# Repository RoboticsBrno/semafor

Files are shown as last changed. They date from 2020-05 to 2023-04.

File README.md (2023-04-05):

# Semafor

Traffic light gadget for outdoor games designed for [Helceletka.cz](https://helceletka.cz/).

## Hardware
Board is based on [ESP8266](https://en.wikipedia.org/wiki/ESP8266) microcontroller and large LEDs. It is powered by our power bank and can be managed via WiFi from the user's phone.

## Software
The software is written in [PlatformIO](https://platformio.org/) and is based on the Arduino framework.

<div align="center">
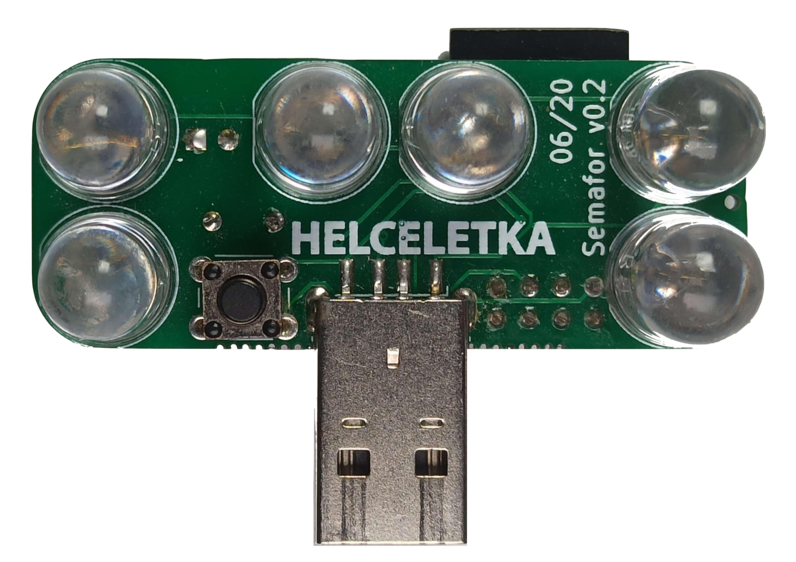
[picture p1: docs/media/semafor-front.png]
  	<td></td>
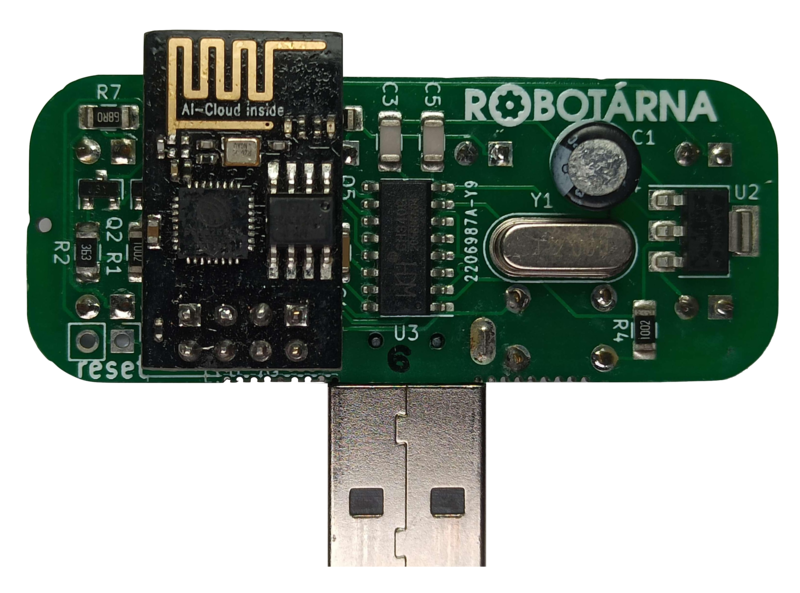
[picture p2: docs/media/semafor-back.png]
	<td></td>
</div>

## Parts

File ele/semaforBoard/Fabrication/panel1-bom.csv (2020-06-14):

Id | Designator | Package | Quantity | Designation | Supplier and ref
1 | REF**,REF**,REF**,REF**,REF**,REF**,REF**,REF**,REF**,REF**,REF**,REF**,REF**,REF**,REF**,REF**,REF**,REF**,REF**,REF**,REF**,REF**,REF**,REF**,REF**,REF**,REF**,REF**,REF**,REF**,REF**,REF**,REF**,REF**,REF**,REF**,REF**,REF**,REF**,REF**,REF**,REF**,REF**,REF**,REF**,REF**,REF**,REF**,REF**,REF**,REF**,REF**,REF**,REF**,REF**,REF**,REF**,REF**,REF**,REF**,REF**,REF**,REF**,REF**,REF**,REF**,REF**,REF**,REF**,REF**,REF**,REF**,REF**,REF**,REF**,REF**,REF**,REF**,REF**,REF**,REF**,REF**,REF**,REF**,REF**,REF**,REF**,REF**,REF**,REF**,REF**,REF**,REF**,REF**,REF**,REF**,REF**,REF**,REF**,REF**,REF**,REF**,REF**,REF**,REF**,REF**,REF**,REF** | NPTH | 108 | NPTH
2 | J1,J1,J1,J1 | PinHeader_1x02_P2.54mm_Vertical | 4 | RESET
3 | D6,D5,D4,D3,D2,D1,D6,D5,D4,D3,D2,D1,D6,D5,D4,D3,D2,D1,D6,D5,D4,D3,D2,D1 | LED_D10.0mm | 24 | LED
4 | Y1,Y1,Y1,Y1 | Crystal_HC49-4H_Vertical | 4 | Crystal
5 | U3,U3,U3,U3 | SOIC-16_3.9x9.9mm_P1.27mm | 4 | CH340G
6 | R10,R4,R3,R2,R1,R10,R4,R3,R2,R1,R10,R4,R3,R2,R1,R10,R4,R3,R2,R1 | R_1206_3216Metric_Pad1.42x1.75mm_HandSolder | 20 | 10k
7 | Q5,Q4,Q3,Q2,Q1,Q5,Q4,Q3,Q2,Q1,Q5,Q4,Q3,Q2,Q1,Q5,Q4,Q3,Q2,Q1 | SOT-23 | 20 | BC817
8 | C5,C3,C5,C3,C5,C3,C5,C3 | C_1206_3216Metric_Pad1.42x1.75mm_HandSolder | 8 | 22pF
9 | C4,C2,C4,C2,C4,C2,C4,C2 | C_1206_3216Metric_Pad1.42x1.75mm_HandSolder | 8 | 100nF
10 | G1,G***,G1,G***,G1,G***,G1,G*** | Robotarna | 8 | LOGO
11 | G2,G2,G2,G2 | Helceletka | 4 | LOGO
12 | J3,J3,J3,J3 | USB_A_CNCTech_1001-011-01101_Horizontal | 4 | USB_A
13 | U1,U1,U1,U1 | ESP-01 | 4 | ESP-01
14 | U2,U2,U2,U2 | SOT-223-3_TabPin2 | 4 | AMS1117-3.3
15 | SW1,SW1,SW1,SW1 | SW_PUSH_6mm | 4 | SW_Push
16 | R9,R8,R9,R8,R9,R8,R9,R8 | R_1206_3216Metric_Pad1.42x1.75mm_HandSolder | 8 | 1k
17 | R7,R6,R5,R7,R6,R5,R7,R6,R5,R7,R6,R5 | R_1206_3216Metric_Pad1.42x1.75mm_HandSolder | 12 | 75R
18 | C1,C1,C1,C1 | CP_Radial_D6.3mm_P2.50mm | 4 | 47uF

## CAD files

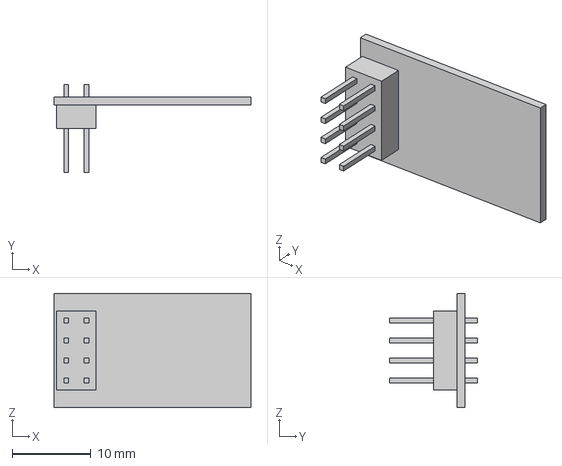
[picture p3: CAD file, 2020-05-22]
hw/ESP-01-fixed v3.step
25.0 x 11.2 x 14.5 mm

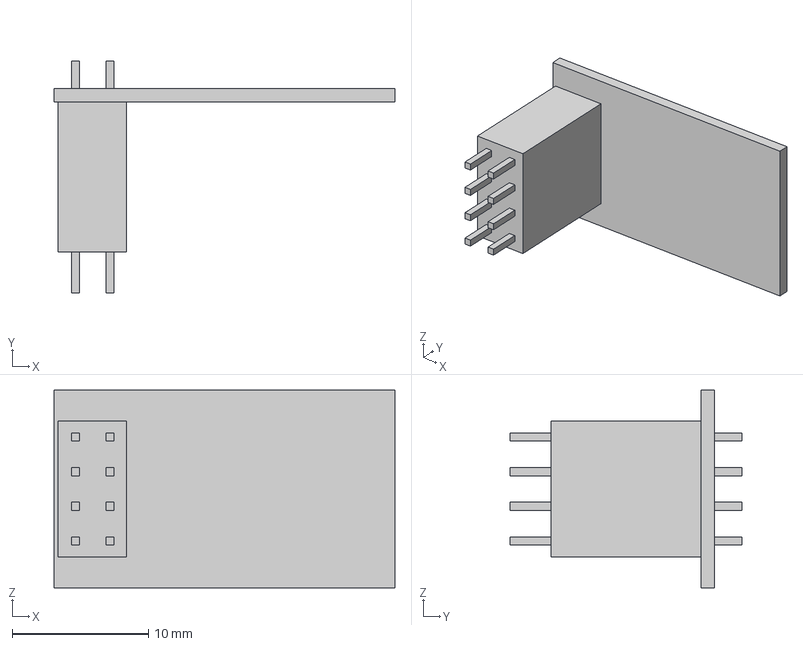
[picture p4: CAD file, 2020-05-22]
hw/ESP-01-detachable v2.step
25.0 x 17.0 x 14.5 mm

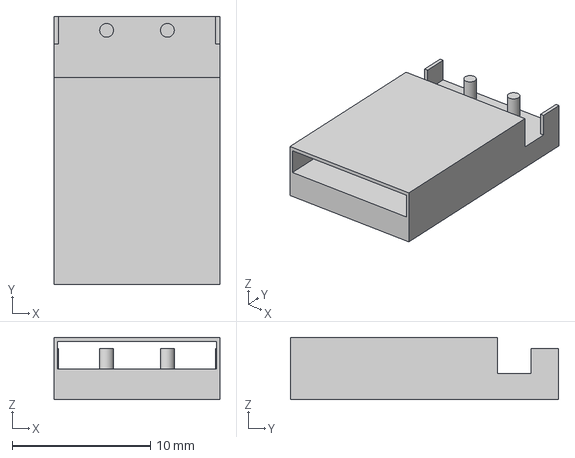
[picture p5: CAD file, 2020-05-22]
hw/USB_A_female_CNCTECH v2.step
12.0 x 19.4 x 4.50 mm

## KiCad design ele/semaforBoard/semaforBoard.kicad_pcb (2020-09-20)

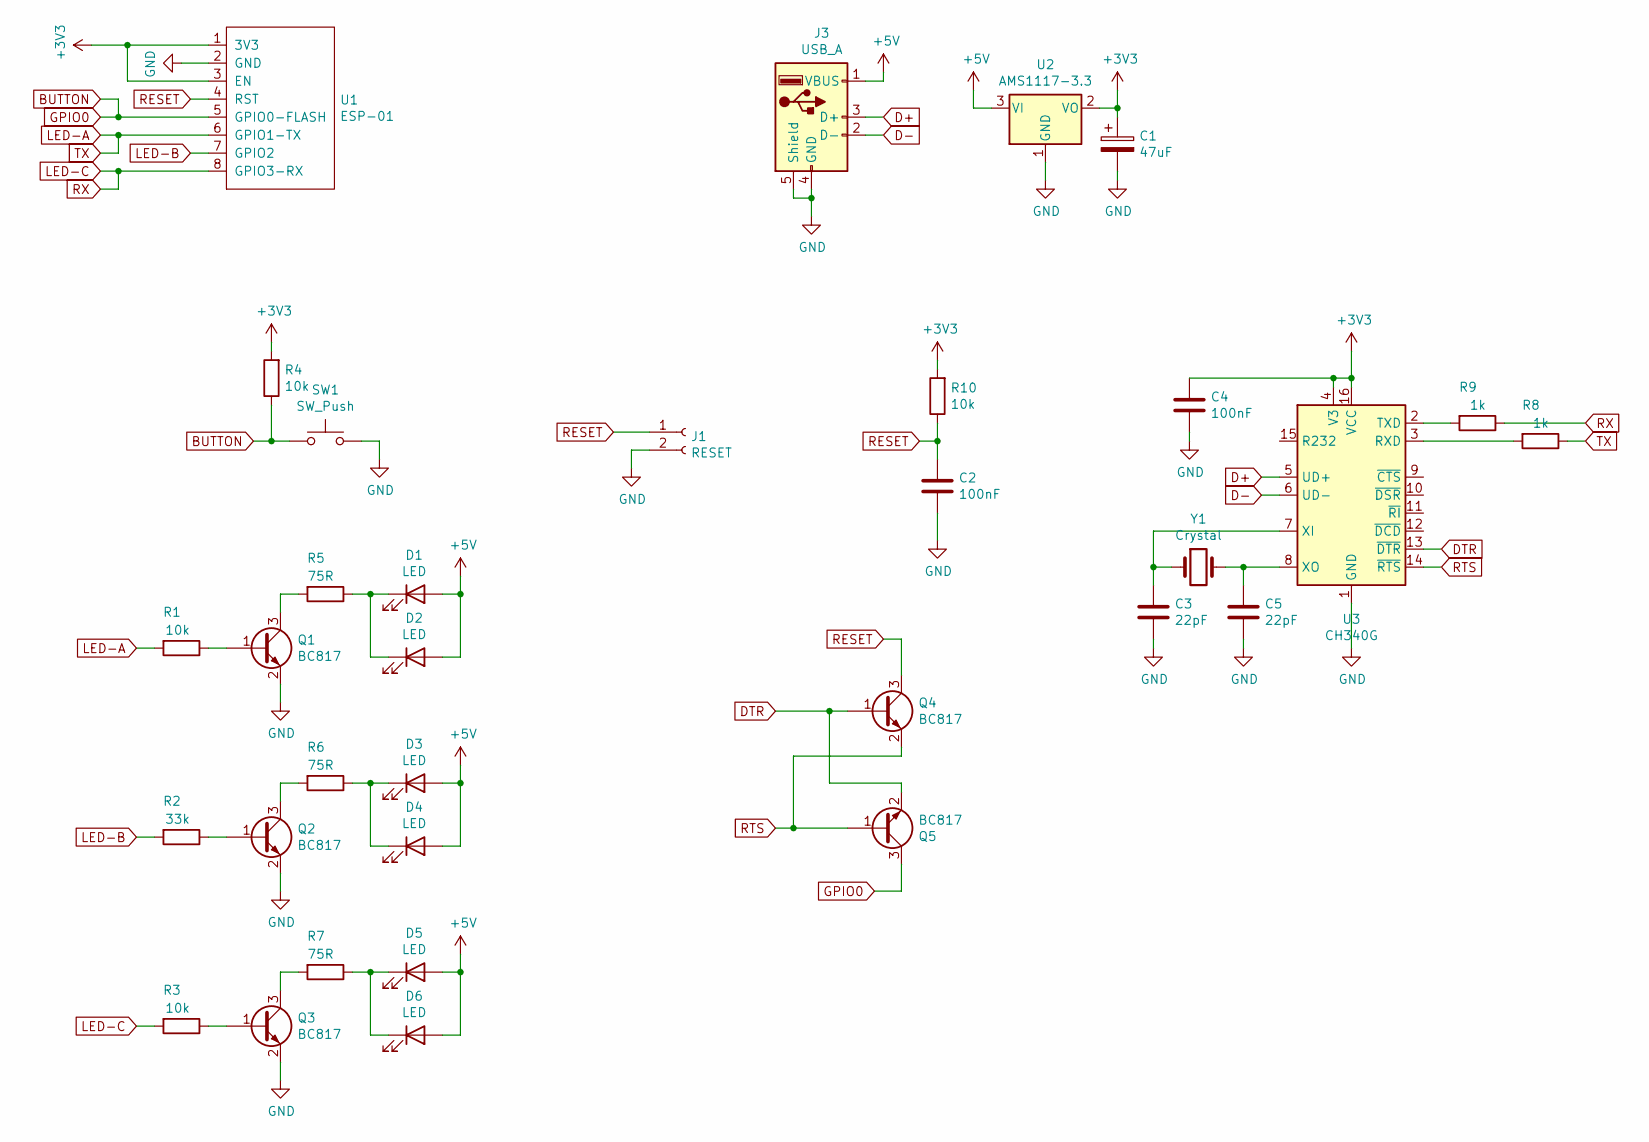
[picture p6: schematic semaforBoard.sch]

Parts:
C1: 47uF; CP_Radial_D6.3mm_P2.50mm
C2, C4: 100nF; C_1206_3216Metric_Pad1.42x1.75mm_HandSolder
C3, C5: 22pF; C_1206_3216Metric_Pad1.42x1.75mm_HandSolder
D1, D2, D3, D4, D5, D6: LED; LED_D10.0mm
J1: RESET; PinHeader_1x02_P2.54mm_Vertical
J3: USB_A; USB_A_CNCTech_1001-011-01101_Horizontal
Q1, Q2, Q3, Q4, Q5: BC817; SOT-23
R1, R3, R4, R10: 10k; R_1206_3216Metric_Pad1.42x1.75mm_HandSolder
R2: 33k; R_1206_3216Metric_Pad1.42x1.75mm_HandSolder
R5, R6, R7: 75R; R_1206_3216Metric_Pad1.42x1.75mm_HandSolder
R8, R9: 1k; R_1206_3216Metric_Pad1.42x1.75mm_HandSolder
SW1: SW_Push; SW_PUSH_6mm
U1: ESP-01
U2: AMS1117-3.3; SOT-223-3_TabPin2
U3: CH340G; SOIC-16_3.9x9.9mm_P1.27mm
Y1: Crystal; Crystal_HC49-4H_Vertical

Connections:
+3V3: C1.1, C4.1, R4.2, R10.2, U1.1 (3V3), U1.3 (EN), U2.2 (VO), U3.4 (V3), U3.16 (VCC)
+5V: D1.2 (A), D2.2 (A), D3.2 (A), D4.2 (A), D5.2 (A), D6.2 (A), J3.1 (VBUS), U2.3 (VI)
BUTTON: Q5.3 (C), R4.1, SW1.1, U1.5 (GPIO0-FLASH)
D+: J3.3 (D+), U3.5 (UD+)
D-: J3.2 (D-), U3.6 (UD-)
DTR: Q4.1 (B), Q5.2 (E), U3.13 (~DTR)
GND: C1.2, C2.2, C3.2, C4.2, C5.2, J1.2, J3.4 (GND), J3.5 (Shield), Q1.2 (E), Q2.2 (E), Q3.2 (E), SW1.2, U1.2 (GND), U2.1 (GND), U3.1 (GND)
LED-A: R1.2, R8.1, U1.6 (GPIO1-TX)
LED-B: R2.2, U1.7 (GPIO2)
LED-C: R3.2, R9.1, U1.8 (GPIO3-RX)
unnamed: C3.1, U3.7 (XI), Y1.1
unnamed: C5.1, U3.8 (XO), Y1.2
unnamed: D1.1 (K), D2.1 (K), R5.1
unnamed: D3.1 (K), D4.1 (K), R6.1
unnamed: D5.1 (K), D6.1 (K), R7.1
unnamed: Q1.1 (B), R1.1
unnamed: Q1.3 (C), R5.2
unnamed: Q2.1 (B), R2.1
unnamed: Q2.3 (C), R6.2
unnamed: Q3.1 (B), R3.1
unnamed: Q3.3 (C), R7.2
unnamed: R8.2, U3.3 (RXD)
unnamed: R9.2, U3.2 (TXD)
RESET: C2.1, J1.1, Q4.3 (C), R10.1, U1.4 (RST)
RTS: Q4.2 (E), Q5.1 (B), U3.14 (~RTS)

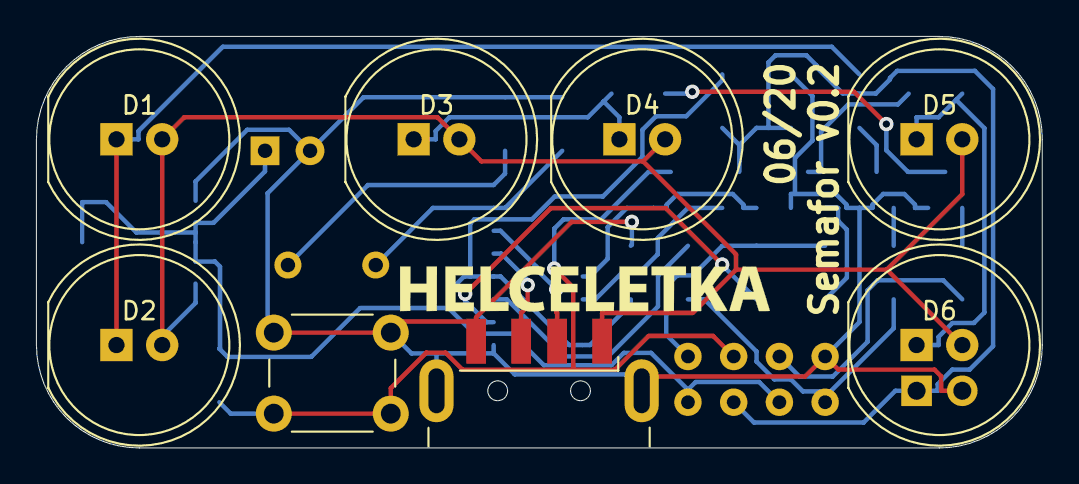
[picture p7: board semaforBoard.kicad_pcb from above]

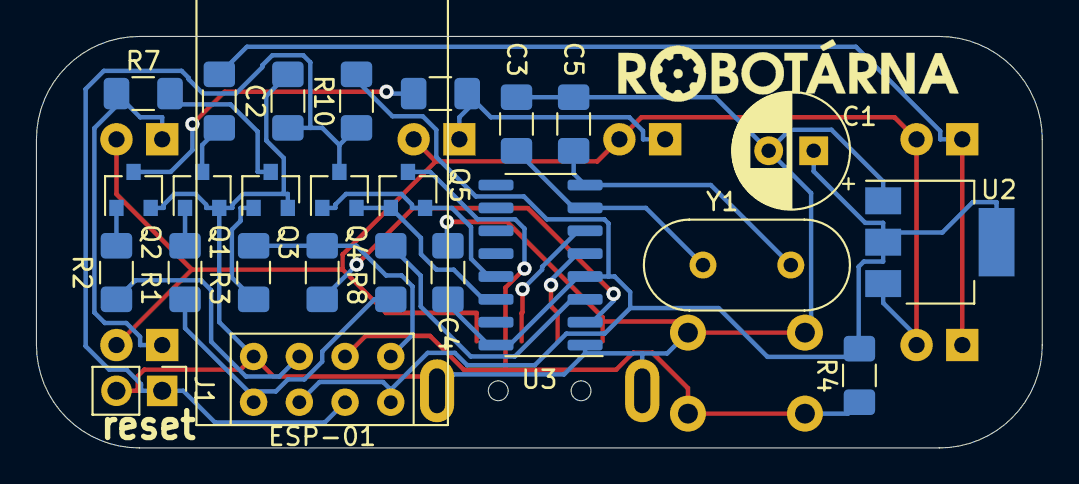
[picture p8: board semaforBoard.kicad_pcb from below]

Board: 2 copper layers, 55.9 x 22.9 mm, 35 parts (26 on the bottom side), 25 nets.

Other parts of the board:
G1: LOGO; Robotarna
G2: LOGO; Helceletka

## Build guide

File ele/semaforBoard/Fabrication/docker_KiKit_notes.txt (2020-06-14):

#Zavoláním následujícího příkazu ve složce, ve které je Dockerfile, se vytvoří image s tag kikit_docker_image
docker image build -t kikit_docker_image .

docker run -it -v D:/pcb:/pcb kikit_docker_image

kikit panelize extractboard --sourcearea 132 67 189 111 semaforBoard.kicad_pcb single.kicad_pcb

kikit panelize grid --space 2.5 --gridsize 4 1 --tabwidth 8 --tabheight 3 --htabs 1 --vtabs 2 --
mousebites 0.5 1 0.25 --radius 1 --tolerance 30 single.kicad_pcb panel1.kicad_pcb

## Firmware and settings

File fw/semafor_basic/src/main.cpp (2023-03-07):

#include "semafor.h"
#include "ArduinoMetronome.hpp"



void setup() {

    uint16_t periodCycle = 20;
    ArduinoMetronome loopMain(periodCycle);
    ArduinoMetronome loopPrint(10000);
    ArduinoMetronome loopSerialRead(50);

    semState sState;

    semaforInit();


    // while (digitalRead(button))
    // {
    //     setLedsAll(1);
    //     delay(50);
    // }

    sState = S_RECEIVE; // first start mode

    while (true)
    {
        dnsServer.processNextRequest();
        server.handleClient();

        if(loopPrint.loopMs()) {
            printInfo(sState);
        }

        if(loopMain.loopMs()) {

            switch (sState)
            {
            case S_RECEIVE:
                // Start game and wait for settings (this mode is automaticly deactivated after settings receive or 2 minutes)

                Serial.printf("\rS_RECEIVE");
                sState = semaforState(); //

                if(settReceive()) { // connec to mother`s ESP and receive settings
                    sState = S_NORMAL; // jump to normal mode after new settings receive
                }

                semaforLoop(); // run normal games parallel with settings receive
                break;

            case S_NORMAL:
                // Normal game mode - WiFi is off and game is running
                Serial.printf("\rS_NORMAL");
                semaforLoop();
                break;

            case S_BRODCAST:
                // Broadcast mode - WiFi is on and game is not running
                // ESP is in mother`s mode with enabled AP and broadcast settings to all ESPs
                // To exit from this mode unplugged power and restart ESP
                Serial.printf("\rS_BRODCAST");
                settBrodcast();
                break;
            }
        }
    }
}

void loop() {}

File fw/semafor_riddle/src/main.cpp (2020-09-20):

#include <ESP8266WiFi.h>
#include <WiFiClient.h>
#include <ESP8266WebServer.h>
#include <DNSServer.h>

#include "stateVector.h"
#include "EEPROM_data.h"
#include "handleHttp.h"

StateVector stateVector;
EEPROM_data stateVector_eeprom(&stateVector, sizeof(stateVector));

// DNS server
uint8_t DNS_PORT = 53;
DNSServer dnsServer;

// Web server
ESP8266WebServer server(80);

char *softAP_ssid = "Hadanka_Vedatori";
const char *softAP_password = "adminadmin";

uint8_t button = 0;   //IO, pulled up, boot fail if low
uint8_t ledPins[] = {1, 2, 3}; //R(TX), G, B(RX)

uint32_t prevCycle = 0;
uint16_t periodCycle = 20;
uint16_t debounce = 1000;
uint16_t flashPeriod = 100;
uint8_t state = 0;
uint32_t ledStateBegin = 0;


void setLed(uint8_t ledGPIO, bool on) {
    analogWrite(ledGPIO, on*stateVector.ledBrightness[0]*4);
}

void setup() {
    Serial.begin(115200);

    for(uint8_t i = 0; i < 3; ++i) {
        pinMode(ledPins[i], OUTPUT);
    }
    pinMode(button, INPUT_PULLUP);

    SPIFFS.begin();
    softApEnable();

    server.on("/", handleRoot);
    server.on("/task2ZcEn7", handleTask2);
    server.on("/task3emibQ", handleTask3);
    server.on("/resultO1mHB", handleResult);
    server.on("/datasave", handlaDataSave);
    server.on("/generate_204", handleRoot);  //Android captive portal. Maybe not needed. Might be handled by notFound handler.
    server.on("/fwlink", handleRoot);  //Microsoft captive portal. Maybe not needed. Might be handled by notFound handler.
    server.onNotFound(handleRoot);
    server.serveStatic("/style.css", SPIFFS, "/style.css");
    server.begin(); // Web server start
}

void loop() {
    dnsServer.processNextRequest();
    server.handleClient();
    if(millis() > prevCycle + periodCycle) {
        prevCycle = millis();
        /*for(uint8_t i = 0; i < state; ++i) {
            digitalWrite(ledPins[i], 1);
        }*/
        /*if((ledStateBegin == 0) && state) {
            ledStateBegin = millis();
        }
        if(state && ((millis() - ledStateBegin) > 2000)) {
            state = 0;
            ledStateBegin = 0;
        }
        printf("%d\n", state);*/
    }
}

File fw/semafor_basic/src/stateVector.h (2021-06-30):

#pragma once

#include <Arduino.h>

struct StateVector{
    uint8_t ledBrightness[3] = {255, 255, 255};
    uint8_t gameMode = 0;
    uint16_t monopolyDelayMin = 10;
    uint16_t monopolyDelayMax = 30;
    uint8_t tdPressShort = 7;
    uint8_t tdPressLong = 12;
    uint8_t holdToGetTimeout = 10;
    uint16_t minutkaTimeSecAll = 60*4; //min
    uint16_t mikrovlnkaTimeSecAll = 60*4; //min
    uint8_t transmittCheckNum = 111;
    bool activeLed = true;
};

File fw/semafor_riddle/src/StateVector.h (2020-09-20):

#ifndef _STATE_VECTOR_
#define _STATE_VECTOR_

#include <Arduino.h>

struct StateVector{
    uint8_t semaforID = 20;
    uint8_t ledBrightness[3] = {255, 255, 255};
    uint8_t currentMode = 0;
    uint16_t monopolyDelayMin = 10;
    uint16_t monopolyDelayMax = 30;
    uint8_t tdPressShort = 7;
    uint8_t tdPressLong = 12;
};
#endif /*_STATE_VETOR_*/

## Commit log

2020-05-22 Test program. First board layout.
    [ESP-01-detachable v2.step, ESP-01-fixed v3.step, USB_A_female_CNCTECH v2.step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]
2020-05-23 Component placement, logos.
    [semaforBoard.dsn, semaforBoard.kicad_pcb, semaforBoard.sch]
2020-05-26 Removed "tlačítko" marking, mount of button now possible on both-sides. Gen. gerbers.
    [semaforBoard-B_Cu.gbr, semaforBoard-B_Mask.gbr, semaforBoard-B_SilkS.gbr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]
2020-06-12 Updated schmatic for CH340G.
    [semaforBoard.kicad_pcb, semaforBoard.sch]
2020-06-13 10mm leds. PCB routed.
    [semaforBoard.dsn, semaforBoard.kicad_pcb, semaforBoard.sch]
2020-06-14 Panelized using kikit and generated fabrication data.
    [panel1-B_Cu.gbr, panel1-B_Mask.gbr, panel1-B_Paste.gbr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]
2020-06-15 Added missing drill file in panel1.zip fabrication file.
2020-07-01 Added flashing to tower defence and currentMode web indication.
2020-07-01 Added brightness setting and fixed state transitions.
    [handleHttp.cpp, main.cpp]
2020-07-02 Fixed monopoly red initial state.
    [main.cpp]
2020-09-20 Changed R2 LED-B-GPIO2 resistor from 10k to 33k for correct boot in KiCad project and excel production files. Added semafor riddle mode.
    [panel1-bom.xlsx, semaforBoard.kicad_pcb, semaforBoard.sch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]
2021-06-23 Fix stateVector filename + try change PIO ini
    [handleHttp.cpp, semafor.cpp, stateVector.h]
2021-06-23 Use metronome, serial-led switch, struct edit
2022-06-03 FIx minutka game restart - close #4
    [semafor.cpp]
